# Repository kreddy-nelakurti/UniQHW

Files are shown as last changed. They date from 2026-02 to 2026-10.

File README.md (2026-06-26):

# UniQHW

The hardware repository for UQ Phone (UniQ)
The Corresponding software component can be found [https://github.com/Benksur/UniQOS](https://github.com/Benksur/UniQOS)

## About

**Supervised by:** Professor Pauline Pounds  
**Institution:** University of Queensland
<div align="center">

### UQ Phone Team (Year 1 - 2025)

| Name | Role |
|---|---|
| **Ty Behnke** | Firmware Design |
| **James Wood** | Hardware Design |
| **Caiyan Jin** | UI/UX Design |
</div>

Any Questions about the PCB and Schematics please direct them to [james.brian.wood@outlook.com](james.brian.wood@outlook.com)

## Production

The V0.2.0 PCB's must be made with the following specifications from JLCPCB

### Main PCB

This 6-Layer PCB must be made with the following

- Via Covering:	Epoxy Filled & Capped
- Min via hole size/diameter:	0.2mm/(0.3/0.35mm)

The following are also required if meeting the full size specifications of UniQ

- PCB Thickness:	0.8mm

Production versions should also be made with the following (Dependant on desired finish)

- Surface Finish:	ENIG Gold Thickness: 2U"
- PCB Color:	Black
- Silkscreen:	White

### Secondary PCB (Cellular Board)

This 4-Layer PCB must be made with the following

- PCB Thickness:	0.6mm
- Via Covering:	Epoxy Filled & Capped
- Min via hole size/diameter:	0.2mm/(0.3/0.35mm)
- Specify Stackup:	yes JLC04061H-2116

If Either the thickness or stackup is to change this boards traces should be redesigned for 50Ohm Impedance 

Production versions should also be made with the following (Dependant on desired finish)

- Surface Finish:	ENIG Gold Thickness: 2U"
- PCB Color:	Black
- Silkscreen:	White

## Current Issues And Improvements

The V0.2.0 PCB currently suffers from several issues which should be rectified on later versions:

- Batter Connector Location: move so it can be inserted and removed indpendantly of the secondary PCB
- SD/SIM Socket: Tie 3.3v SD card rail to insertion detection to prevent hot-plugging
- Debug Pads: Consider moving to provide easier access without interferance from screen
- Soft Power: Add soft power switch for more agressive power-off functionality and safer power-downs

The following may also be investigated for benefit 
- Improve Display: Ideally Display utilises a parellel interface, this needs more investigation
- Audio Volume: Current speaker is quiet, this should be investigated further to see if this can be remediated in firmware first
- USB Support: Add USB data connectivity to the device for file transfer or programming, this may resolve debug pad issues
- BT Audio: this poses significant challenges, although may be worth while, investigate further

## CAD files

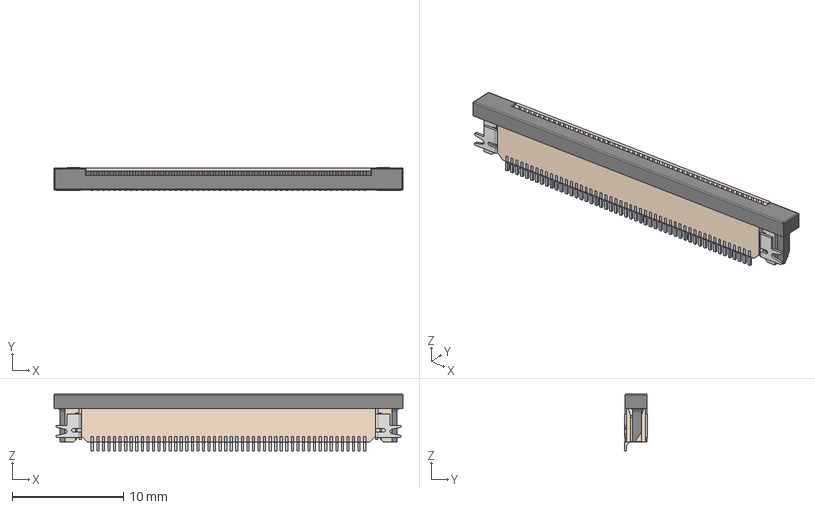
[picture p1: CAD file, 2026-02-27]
Components/6871XX14022_68715014022/6871XX14022_68715014022.step
31.4 x 2.10 x 5.10 mm
6871xx14022_PIN x 50
6871xx14022_Patte
6871xx14022_Patte_2
68715014022_CAP

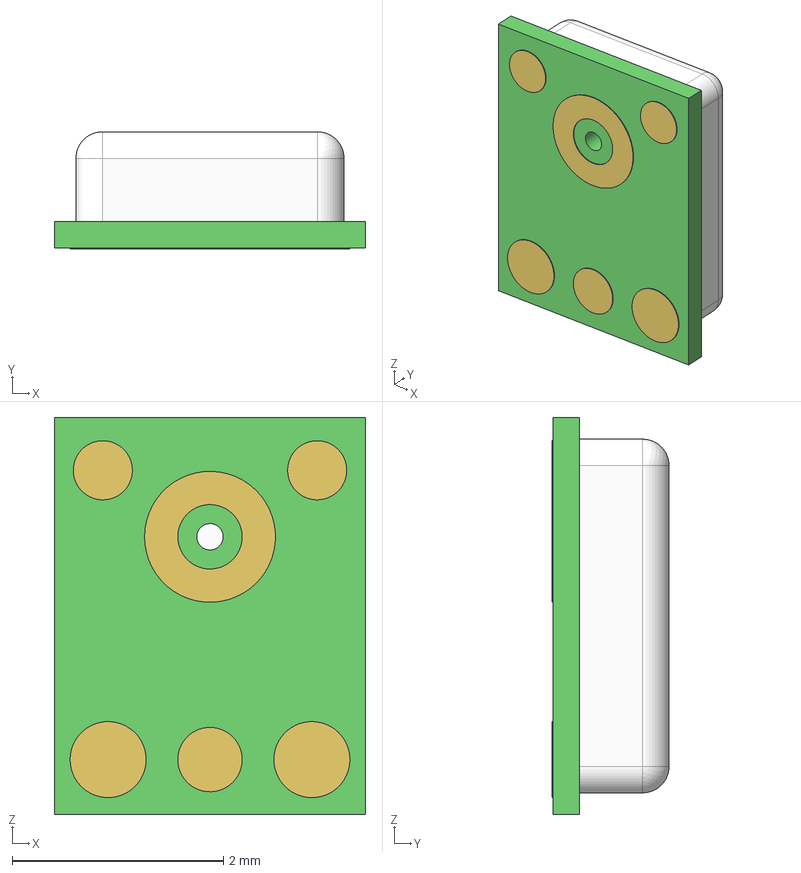
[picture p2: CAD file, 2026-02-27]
Components/AMM-3738-B-R/AMM-3738-B-R.step
2.95 x 1.11 x 3.76 mm

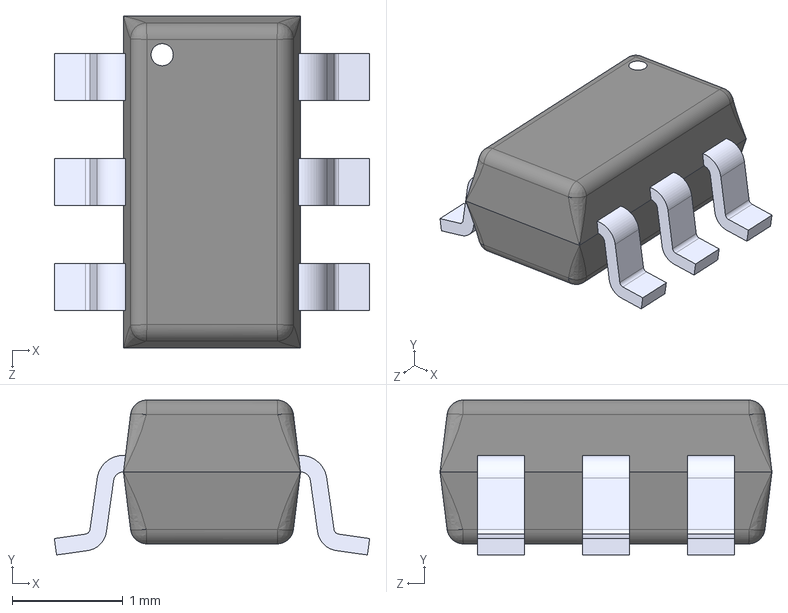
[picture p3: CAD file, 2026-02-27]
Components/BCR420UW6-7/BCR420UW6-7.step
2.85 x 1.40 x 3.00 mm

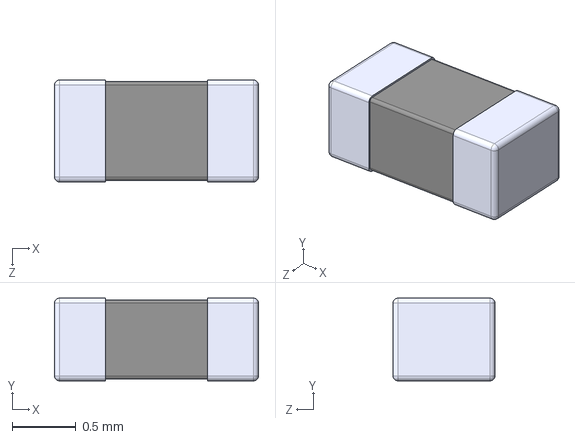
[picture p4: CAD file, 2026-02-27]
Components/BLM18SG221TN1D/BLM18SG221TN1D.step
1.60 x 0.65 x 0.8 mm

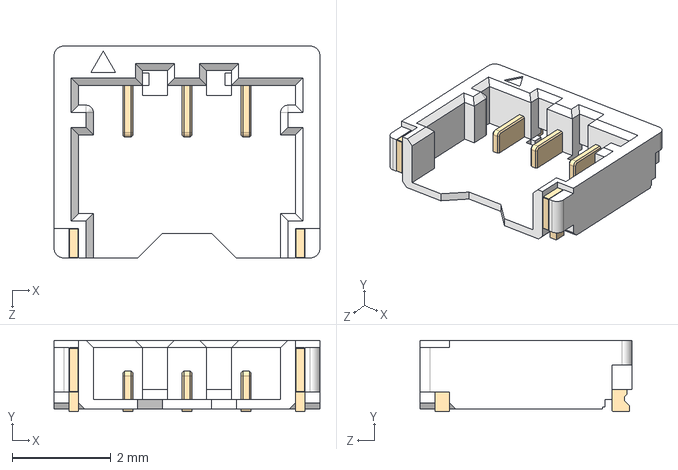
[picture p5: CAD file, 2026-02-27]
Components/BM03B-ACHSS-GAN-TF_LF__SN_/BM03B-ACHSS-GAN-TF_LF__SN_.step
5.40 x 1.45 x 4.30 mm

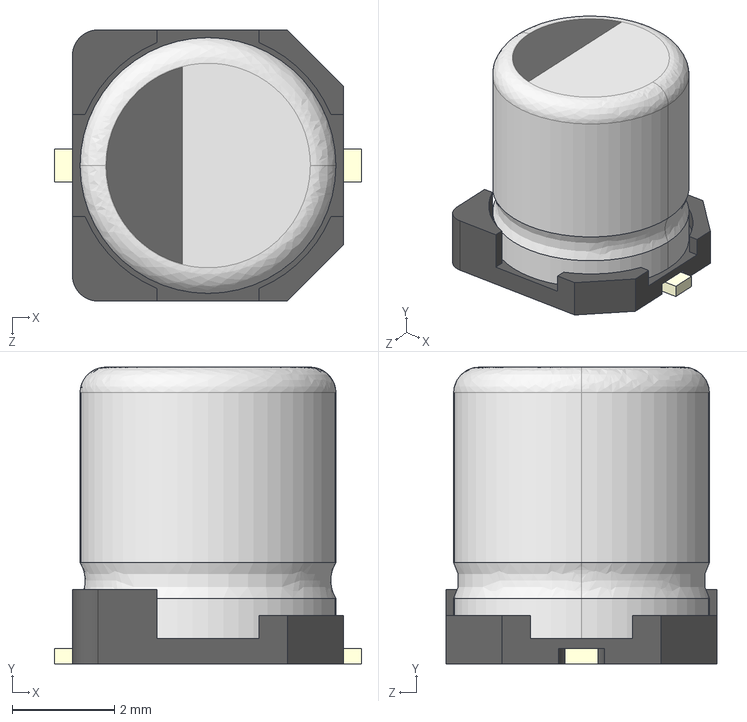
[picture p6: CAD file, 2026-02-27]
Components/Capacitors/EEE1CA470WR.step
6.00 x 5.80 x 5.30 mm

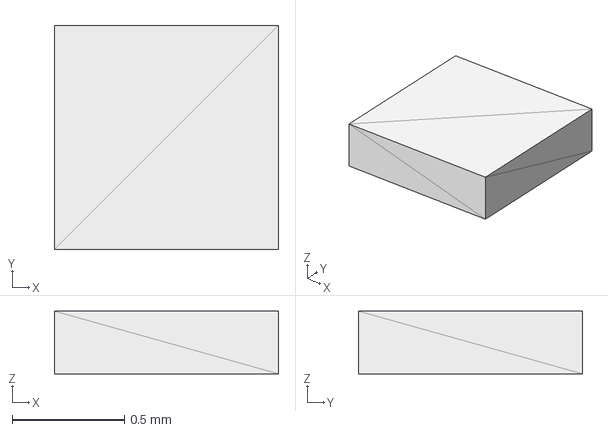
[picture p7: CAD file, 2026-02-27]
Components/custom_footprints_3d/XL-1010RGBC-WS2812B.step
1.00 x 1.00 x 0.28 mm

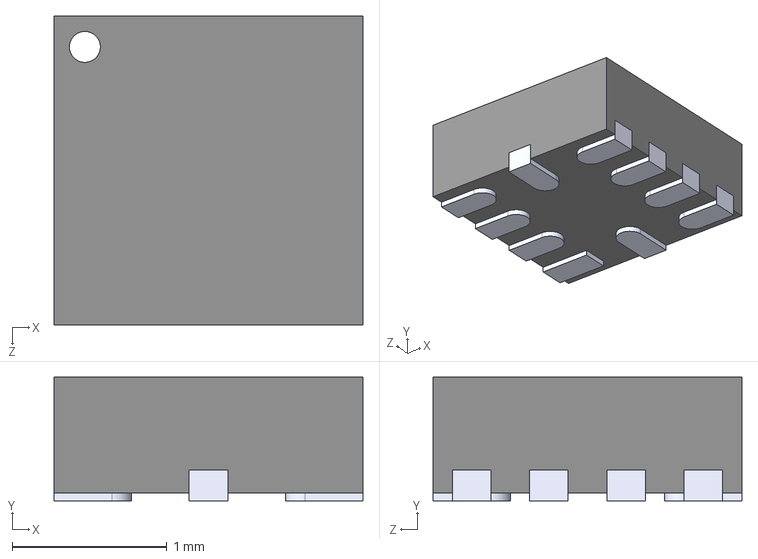
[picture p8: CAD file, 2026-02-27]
Components/DRV2603RUNR/DRV2603RUNR.step
2.00 x 0.8 x 2.00 mm

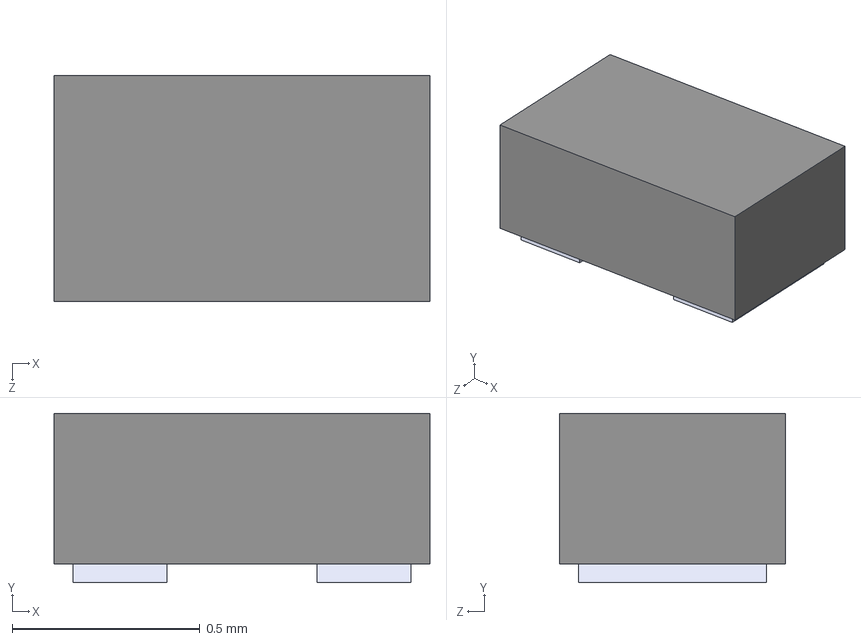
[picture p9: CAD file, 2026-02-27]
Components/ESD321DPYR/ESD321DPYR.step
1.00 x 0.45 x 0.6 mm

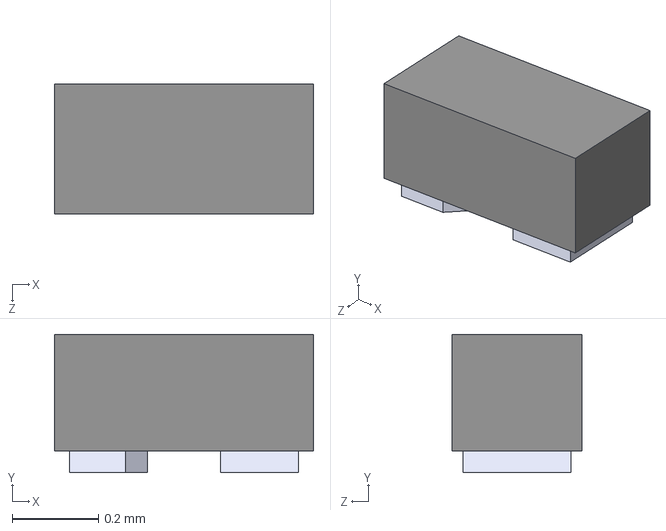
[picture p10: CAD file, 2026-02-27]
Components/ESD441DPLR/ESD441DPLR.step
0.6 x 0.32 x 0.3 mm

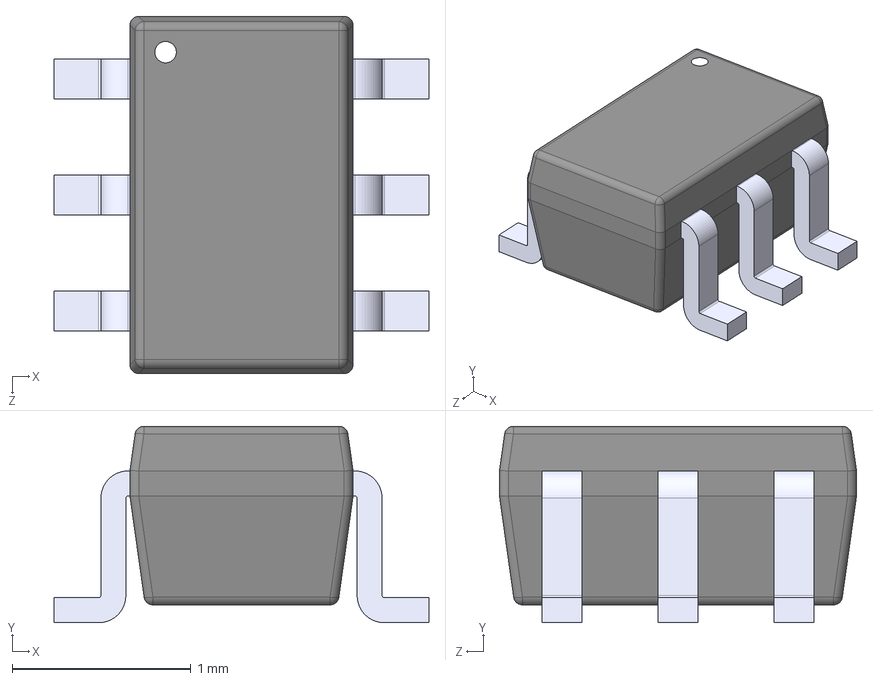
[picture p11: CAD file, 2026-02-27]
Components/ESDA6V1-5W6/ESDA6V1-5W6.step
2.10 x 1.10 x 2.00 mm

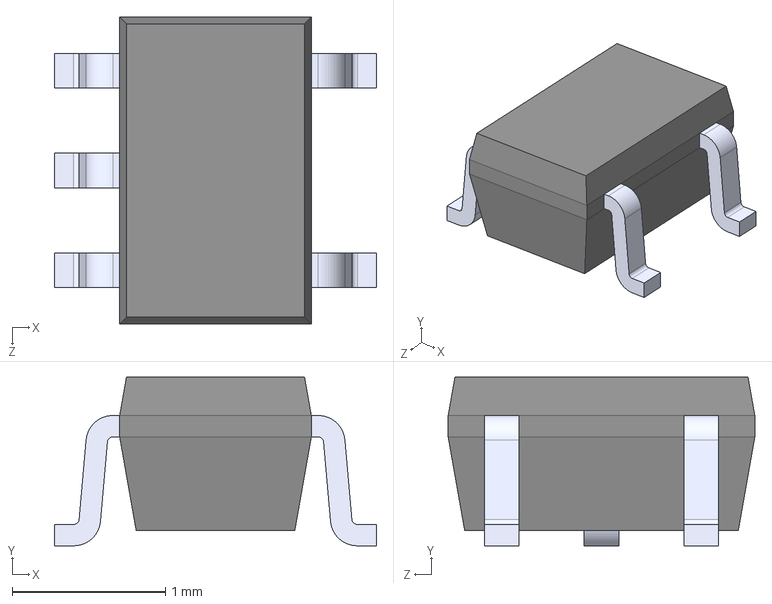
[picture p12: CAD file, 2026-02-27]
Components/ESDA6V1W5/ESDA6V1W5.step
2.10 x 1.10 x 2.00 mm

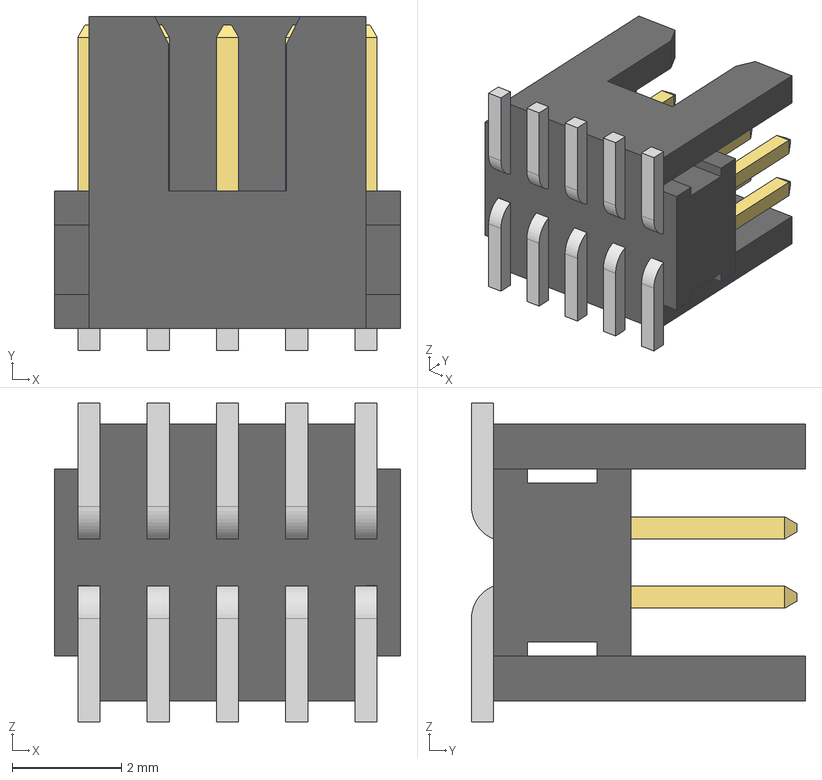
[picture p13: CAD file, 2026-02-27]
Components/FTSH-105-XX-X-DV/FTSH-105-XX-X-DV.step
6.35 x 6.12 x 5.84 mm
FTSH-105-01-L-DV-K-TR_body
FTSH-105-01-L-DV-K-TR_pins1
FTSH-105-01-L-DV-K-TR_pins2

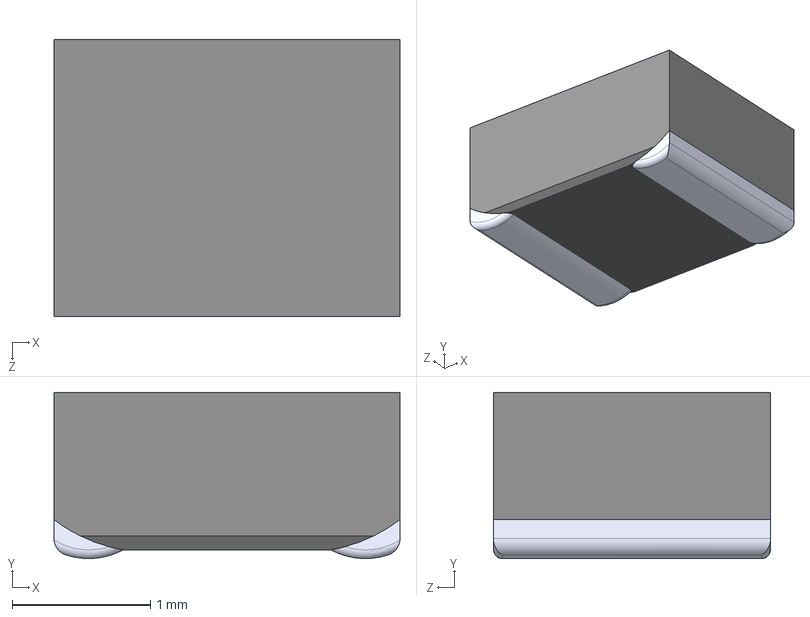
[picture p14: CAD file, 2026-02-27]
Components/Inductors/MAMK2520T3R3M.step
2.50 x 1.20 x 2.00 mm

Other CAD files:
Components/KP15B-6S-SF_800_/KP15B-6S-SF_800_.step
Components/LightOn-LEDs/LTST-C193KRKT-5A.step
Components/MMBT3904LP-7/MMBT3904LP-7.step
Components/MMBT3904LT1G/MMBT3904LT1G.step
Components/0532610371/0532610371.step
Components/1042391430/1042391430.step
Components/124018312112A/124018312112A_alt.step
Components/20279-001E-03/20279-001E-03.step
Components/503398-1892/503398-1892.step
Components/513382474/513382474.stp
Components/559092474/559092474.step
Components/BQ27441DRZR-G1A/BQ27441DRZR-G1A.step
Components/LP414565.step
Components/MAX17048G_T10/MAX17048G_T10.step
Components/MCP73871-2CCI_ML/MCP73871-2CCI_ML.step
Components/MMSZ5231BT1G/SOD-123_ONS.step
Components/MPZ2012S221AT000/MPZ2012S221AT000.step
Components/PCA9306DQER/PCA9306DQER.step
Components/RC7620_1104625/5302491_asm.stp
Components/S3B-PH-SM4-TB_LF__SN_/S3B-PH-SM4-TB_LF__SN_.step
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

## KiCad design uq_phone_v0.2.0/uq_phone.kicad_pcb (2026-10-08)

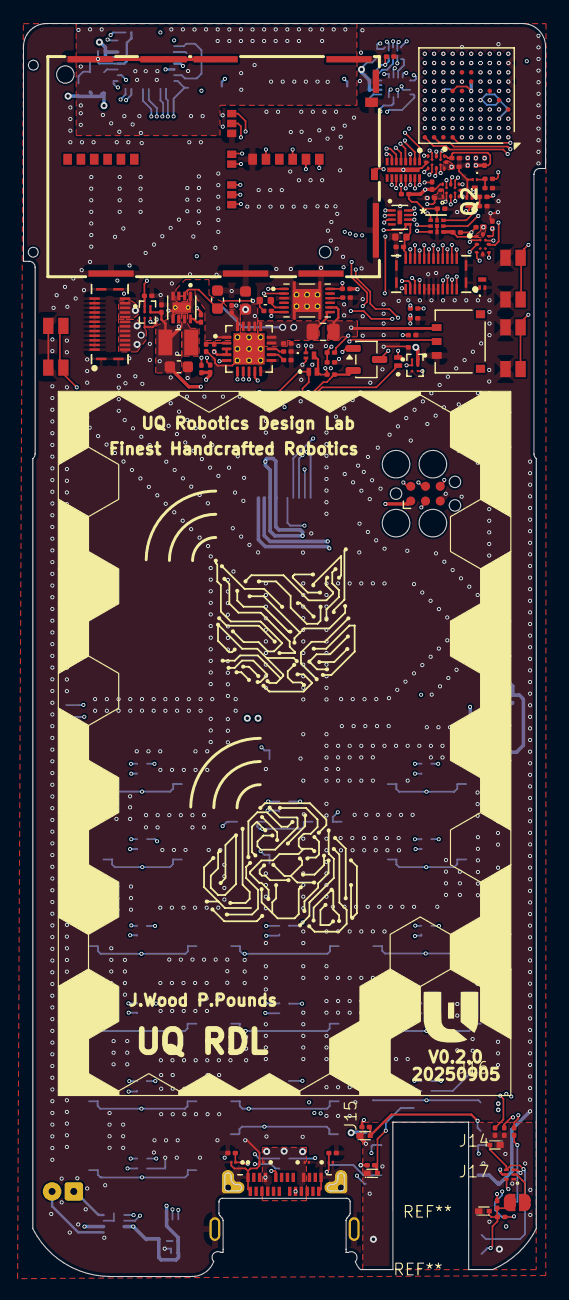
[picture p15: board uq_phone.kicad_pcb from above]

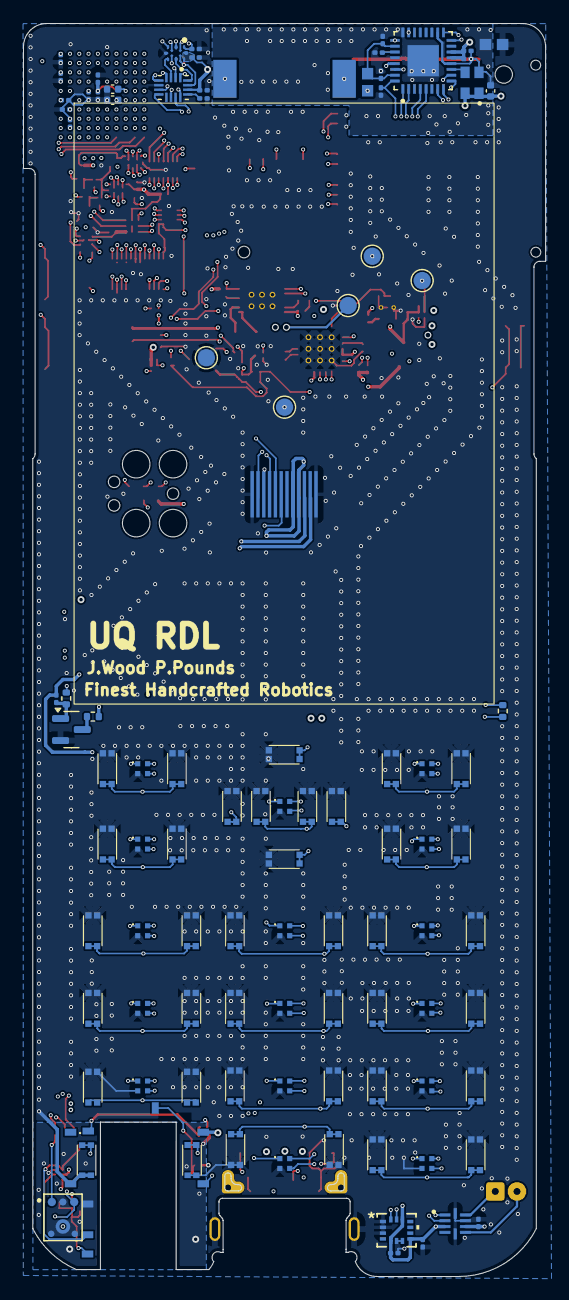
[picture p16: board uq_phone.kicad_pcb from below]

Board: 6 copper layers, 45.0 x 108.0 mm, 200 parts (100 on the bottom side), 182 nets.

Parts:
ART: Art_large
C1, C3: 10uF; C_0603_1608Metric
C2: 22uF; C_0603_1608Metric
C4, C7, C14, C36, C39, C40, C41, C42, C43, C44: 4.7uF; C_0201_0603Metric
C5: 470pF; C_0402_1005Metric
C6, C22, C23, C30, C37, C45, C47, C48, C49: 1uF; C_0201_0603Metric
C15, C16, C17, C18, C19, C20, C21, C28, C29, C31, C32, C34, C35, C38, C50, C51, C54, C55, C56, C57, C58, C59, C60: 100nF; C_0201_0603Metric
C25, C26: 2.2uF; C_0402_1005Metric
C33: 33pF; C_0402_1005Metric
C46: 10nF; C_0402_1005Metric
D2, D12: BAT54LP-7; DESD3V3S1BL7B
D4, D5, D6, D7: ESD441DPLR; DIODFN60X30X32-2N
D8, D9, D10, D11: ESD5451X; WBFBP-02C_L1.0-W0.6-BI
DISP1: HS20HS072RX; Display
FB1, FB2: BLM18SG221TN1D; BEADC1608X65N
J2: 124018312112A; AMPHENOL_124018312112A
J3: BM03B-ACHSS-GAN-TF_LF__SN_; JST_BM03B-ACHSS-GAN-TF_LF__SN_
J6: Conn_ARM_SWD_TagConnect_TC2030; Tag-Connect_TC2030-IDC-FP_2x03_P1.27mm_Vertical
J7, J9: 559092474; CON_559092474
J8: MCS-302S-C1; SIM-SMD_MCS-302S-C1
J13, J14, J15, J16, J17: Conn_01x01; Breakout_Mating_Pad
JP1: SolderJumper; SolderJumper-2_P1.3mm_Open_RoundedPad1.0x1.5mm
L1: 3.3uH; INDC2520X120N
LED1, LED3, LED4, LED5, LED6, LED7, LED8, LED9, LED10, LED11, LED12, LED13, LED14, LED15, LED16, LED17: XL-1010RGBC; XL-1010RGBC-WS2812B
LED2: XL-1010RGBC; XL-1010RGBC-Alt
M1: C08-00A; Motor_8mm
MK1: AMM-3738-B-R; MIC_AMM-3738-B-R
OSC1: OT7EL89CJI-111YLC-19.2M; OSC-SMD_4P-L2.0-W1.6-BL
Q1: MMBT3904LP-7; DFN101X61X53-3N
Q2, Q5, Q6: MMBT3904LP-7; MMBT3904LP7
Q3: S8050; SOT-23
Q4: DMP2035U-7; SOT-23-3
R1, R7, R11, R28, R29, R30: 100k; R_0201_0603Metric
R2, R3, R6: 5.1k; R_0201_0603Metric
R4, R16, R17, R22, R31: 4.7k; R_0201_0603Metric
R5: 270k; R_0201_0603Metric
R8, R20, R21, R23, R24, R25, R33, R37: 10k; R_0201_0603Metric
R9: 10m; R_0805_2012Metric
R10, R36: 2.2k; R_0201_0603Metric
R18, R19, R34: 47k; R_0201_0603Metric
R26: 1k; R_0402_1005Metric
R27: 5R; R_0402_1005Metric
R42: 330R; R_0402_1005Metric
SP1: MCABS-258-RC
SW1, SW2, SW3, SW4, SW5, SW7, SW8, SW9, SW10, SW11, SW12, SW13, SW14, SW15, SW17, SW18, SW19, SW20, SW21, SW23, SW24, SW25, SW26, SW27, SW28, SW29, SW30, SW31, SW32, SW33, SW34, SW35, SW36, SW37, SW38, SW39, SW40, SW41: SKTAAAE010
SW6, SW16, SW22: SKSCLCE010
TP1, TP2, TP3, TP5, TP6: TestPoint; TestPoint_Pad_D1.5mm
U1: TPS62162DSGR; SON50P200X200X80-9N
U2: MCP73871-2CCI_ML; QFN50P400X400X100-21N
U3: BQ27441DRZR-G1A; IC_BQ27441DRZR-G1A
U5: TCA9509MRVHR; RVH8_0P4X0P4
U6: STM32H723VGHx; TFBGA-100_8x8mm_Layout10x10_P0.8mm
U7, U15: TPS22964CYZPR; IC_SN74LVC2G34YZPR
U8: TPD3F303DQDR; SON40P170X135X80-9N
U9: AZV5001RA4-7; DFN1210P6X_L1.2-W1.0-P0.40-BL
U10: TPD8F003DQDR; SON40P135X330X80-17N
U11: LSM6DSVTR; LGA14-L_2P59X3P1X0P5_STM
U12: DRV2603RUNR; QFN50P200X200X80-10N
U13: TS3A5018RSVR; QFN40P260X180X55-16N
U14: NAU88C22YG; QFN50P500X500X80-33N
U17: TXU0204DTRR; DTR0012A-MFG
U18: TXU0304DTRR; DTR0012A-MFG
U19, U20: TXU0104DTRR; DTR0012A-MFG

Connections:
+1.8V: C28.1, C38.1, C41.1, C42.1, C46.1, C50.1, C55.1, C57.1, C59.1, J7.20, J7.21, J7.22, J7.23, OSC1.1 (Tri-state), OSC1.4 (VDD), U5.1 (VCCA), U5.5 (EN), U9.5 (Vcc), U13.14 (V+), U14.13 (VDDC), U14.14 (VDDB), U17.11 (VCCB), U17.12 (OE), U18.1 (VCCA), U18.12 (OE), U19.11 (VCCB), U19.12 (OE), U20.1 (VCCA), U20.12 (OE)
+3.3V: C2.1, C14.1, C15.2, C16.2, C17.2, C18.2, C19.2, C21.2, C22.1, C29.1, C30.1, C34.1, C35.1, C51.1, C54.1, C56.1, C58.1, C60.1, DISP1.8 (IOVCC), DISP1.9 (VCC), FB2.1, J6.1 (VCC), L1.2, R1.2, R4.2, R6.2, R22.2, R23.2, R24.2, R25.2, TP2.1, U1.6 (VOS), U5.8 (VCCB), U6.B2 (VBAT), U6.D2 (VDD), U6.F4 (VDD), U6.F5 (VDD), U6.F7 (PDR_ON), U6.H1 (VDDA), U6.K1 (VDD), U7.A2 (VIN), U7.B2 (VIN), U11.5 (VDD_IO), U11.8 (VDD), U11.12 (CS), U12.3 (LRA/~ERM), U12.7 (VDD), U15.A2 (VIN), U15.B2 (VIN), U17.1 (VCCA), U18.11 (VCCB), U19.1 (VCCA), U20.11 (VCCB)
+3.3V_SW: C31.1, DISP1.10 (LEDA), LED1.2 (VDD), LED2.2 (VDD), LED3.2 (VDD), LED4.2 (VDD), LED5.2 (VDD), LED6.2 (VDD), LED7.2 (VDD), LED8.2 (VDD), LED9.2 (VDD), LED10.2 (VDD), LED11.2 (VDD), LED12.2 (VDD), LED13.2 (VDD), LED14.2 (VDD), LED15.2 (VDD), LED16.2 (VDD), LED17.2 (VDD), R21.2, TP5.1, U15.A1 (VOUT), U15.B1 (VOUT)
AGND: C37.1, C39.2, C40.2, C43.2, C44.2, C45.2, D8.1, D9.1, D10.1, D11.1, FB1.2, J14.1, MK1.2 (GND), MK1.3 (GND__1), MK1.5 (GND__2), MK1.6_1 (GND__3), MK1.6_2 (GND__4), U9.1 (GND), U9.3 (G_Detect), U14.24 (VSSSPK), U14.28 (VSSA), U14.33 (EXP)
AUD_BCLK: U13.5 (COM2), U14.8 (BCLK)
AUD_IN: U13.7 (COM3), U14.9 (ADCOUT)
AUD_OUT: U13.10 (COM4), U14.10 (DACIN)
AUD_SCL: U5.2 (SCLA), U14.16 (SCLK)
AUD_SDA: U5.3 (SDAA), U14.17 (SDIO)
AUD_SW_H: U6.K10 (PD12), U19.2 (A1)
AUD_SW_L: R28.2, U13.15 (IN), U19.10 (B1Y)
AUD_SYNC: U13.2 (COM1), U14.7 (FS)
BAT_THERM: J3.2, U2.5 (THERM)
DISP_BL: R26.2, U6.J3 (PA6)
DISP_CS: DISP1.2 (CS), U6.J8 (PB13)
DISP_DC: DISP1.3 (RS), U6.H8 (PD14)
DISP_LEDK: DISP1.11 (LEDK), R27.2
DISP_RESET: DISP1.6 (RESET), U6.G8 (PD15)
DISP_SCL: DISP1.4 (SCL), U6.J6 (PE12)
DISP_SDA: DISP1.5 (SDA), U6.G7 (PE14)
FUEL_GPO: R6.1, U3.12 (GPOUT), U6.G9 (PD11)
GND: C1.1, C2.2, C3.2, C4.2, C5.2, C6.2, C7.2, C14.2, C15.1, C16.1, C17.1, C18.1, C19.1, C20.1, C21.1, C22.2, C23.2, C25.2, C26.2, C28.2, C29.2, C30.2, C31.2, C32.2, C33.2, C34.2, C35.2, C38.2, C41.2, C42.2, C46.2, C50.2, C51.2, C54.2, C55.2, C56.2, C57.2, C58.2, C59.2, C60.2, D4.2, D5.2, D6.2, D7.2, DISP1.1 (GND), DISP1.12 (GND), FB1.1, J2.A1 (GND_A), J2.A12 (GND_A__1), J2.B1 (GND_B), J2.B12 (GND_B__1), J2.SH1 (SHIELD), J2.SH2 (SHIELD__1), J2.SH3 (SHIELD__2), J2.SH4 (SHIELD__3), J3.1, J6.5 (GND), J7.1, J7.2, J7.3, J7.4, J7.5, J7.6, J7.7, J7.8, J7.9, J7.10, J7.11, J7.12, J7.24, J7.P1, J7.P2, J7.P3, J7.P4, J8.6 (VSS), J8.12 (SIM_1_GND), J8.22 (S/GND), J8.23 (GND), J9.5, J9.6, J9.7, J9.8, J9.P1, J9.P2, J9.P3, J9.P4, LED1.3 (GND), LED2.3 (GND), LED3.3 (GND), LED4.3 (GND), LED5.3 (GND), LED6.3 (GND), LED7.3 (GND), LED8.3 (GND), LED9.3 (GND), LED10.3 (GND), LED11.3 (GND), LED12.3 (GND), LED13.3 (GND), LED14.3 (GND), LED15.3 (GND), LED16.3 (GND), LED17.3 (GND), OSC1.2 (GND), Q1.2, Q2.2, Q3.2, Q5.2, Q6.2, R2.1, R3.1, R7.1, R8.1, R10.2, R11.1, R18.1, R19.1, R20.1, R28.1, R29.1, R33.1, R34.1, SW1.2, SW1.4, SW2.2, SW2.4, SW3.2, SW3.4, SW4.2, SW4.4, SW5.2, SW5.4, SW6.3, SW6.4, SW7.2, SW7.4, SW8.2, SW8.4, SW9.2, SW9.4, SW10.2, SW10.4, SW11.2, SW11.4, SW12.2, SW12.4, SW13.2, SW13.4, SW14.2, SW14.4, SW15.2, SW15.4, SW16.3, SW16.4, SW17.2, SW17.4, SW18.2, SW18.4, SW19.2, SW19.4, SW20.2, SW20.4, SW21.2, SW21.4, SW22.1, SW22.2, SW23.2, SW23.4, SW24.2, SW24.4, SW25.2, SW25.4, SW26.2, SW26.4, SW27.2, SW27.4, SW28.2, SW28.4, SW29.2, SW29.4, SW30.2, SW30.4, SW31.2, SW31.4, SW32.2, SW32.4, SW33.2, SW33.4, SW34.2, SW34.4, SW35.2, SW35.4, SW36.2, SW36.4, SW37.2, SW37.4, SW38.2, SW38.4, SW39.2, SW39.4, SW40.2, SW40.4, SW41.2, SW41.4, TP6.1, U1.1 (PGND), U1.4 (AGND), U1.5 (FB), U1.9 (EXP), U2.10 (VSS__1), U2.11 (VSS), U2.21 (EP), U3.3 (VSS), U3.13 (EXP), U5.4 (GND), U5.9 (EPAD), U6.C2 (VSS), U6.E4 (VSS), U6.E5 (VSS), U6.E6 (VSS), U6.G1 (VSSA), U6.J1 (VSS), U7.C1 (GND), U8.9 (GND), U10.17 (GND), U11.1 (SDO/SA0), U11.2 (SDX), U11.3 (SCX), U11.6 (GND), U11.7 (GND), U12.5 (GND), U12.8 (GND__1), U12.10 (GND__2), U13.6 (GND), U14.12 (VSSD), U14.18 (MODE), U15.C1 (GND), U17.6 (GND), U18.6 (GND), U19.6 (GND), U20.6 (GND)
HP_DET: U9.6 (OUT), U20.5 (A4)
HP_DET_MCU: U6.J10 (PD13), U20.7 (B4Y)
HP_LEFT: C48.1, U14.30 (LHP)
HP_LEFT_DET: D8.2, J17.1, U9.4 (L_Detect)
HP_MIC: C47.1, U14.4 (RMICP)
HP_MIC_GND: C45.1, U14.5 (RMICN)
HP_RIGHT: C49.1, U14.29 (RHP)
LED_DATA: R42.2, U6.K2 (PA3)
MCP_OUT: C4.1, Q4.2 (S), R30.1, U2.1 (OUT), U2.20 (OUT__1)
MCP_PG: U2.6 (~PG), U6.G10 (PB15)
MCP_STAT1: R24.1, U2.8 (STAT1/*LBO), U6.H10 (PB14)
MCP_STAT2: R23.1, U2.7 (STAT2), U6.H9 (PD10)
MCU_AUD_BCLK_H: U6.H3 (PA5), U19.5 (A4)
MCU_AUD_BCLK_L: U13.3 (NC2), U19.7 (B4Y)
MCU_AUD_OUT_L: U13.12 (NC4), U19.8 (B3Y)
MCU_AUD_OUT_L_H: U6.K3 (PA7), U19.4 (A3)
MCU_AUD_SYNC_H: U6.G3 (PA4), U19.3 (A2)
MCU_AUD_SYNC_L: U13.16 (NC1), U19.9 (B2Y)
MCU_CTS: U6.C10 (PA11), U17.4 (A3Y)
MCU_DCD: U6.C7 (PD3), U18.8 (B3Y)
MCU_DSR: U6.D9 (PA8), U18.9 (B2Y)
MCU_DTR: U6.D8 (PD0), U18.7 (B4)
MCU_PWR_LATCH: R31.2, U6.J4 (PB0)
MCU_RI: U6.F10 (PC6), U18.10 (B1Y)
MCU_RTS: U6.B10 (PA12), U17.3 (A2)
MCU_RXD: U6.D10 (PA10), U17.5 (A4Y)
MCU_TXD: U6.C9 (PA9), U17.2 (A1)
MIC_BIAS: C44.1, MK1.4 (VDD), R36.2, U14.32 (MICBIAS)
MIC_GND: C37.2, U14.2 (LMICN)
MIC_OUT: C36.2, U14.1 (LMICP)
MIC_PIN: C47.2, D11.2, J13.1, JP1.1 (A), R36.1
MOB_AUD_BCLK: J9.9, U13.4 (NO2)
MOB_AUD_IN: J9.10, U13.8 (NO3)
MOB_AUD_OUT: J9.11, U13.11 (NO4)
MOB_AUD_SYNC: J9.12, U13.1 (NO1)
MOB_CTS: J9.18, U17.8 (B3)
MOB_DCD: J9.14, U18.4 (A3)
MOB_DSR: J9.15, U18.3 (A2)
MOB_DTR: J9.13, U18.5 (A4Y)
MOB_PWR: J9.1, Q1.3
MOB_PWR_CTL: R16.2, U6.A2 (PC13)
MOB_RI: J9.20, U18.2 (A1)
MOB_RST: J9.2, Q2.3
MOB_RST_CTL: R17.2, U6.A1 (PC14)
MOB_RTS: J9.17, U17.9 (B2Y)
MOB_RXD: J9.19, U17.7 (B4)
MOB_SAFE_PWR_REMOVE_H: U6.J9 (PD9), U20.9 (B2Y)
MOB_SAFE_PWR_REMOVE_L: J9.3, U20.3 (A2)
MOB_TXD: J9.16, U17.10 (B1Y)
MOB_WAKE_H: U6.K9 (PD8), U20.10 (B1Y)
MOB_WAKE_L: J9.4, U20.2 (A1)
unnamed: C25.1, U6.E7 (VCAP)
unnamed: C26.1, U6.F8 (VCAP)
unnamed: D2.2 (A), Q4.1 (G), Q5.3, R30.2
unnamed: D2.1 (K), D12.1 (K), SW22.3, SW22.4
unnamed: D7.1, J2.A5 (CC1), R2.2
unnamed: D6.1, J2.B5 (CC2), R3.2
unnamed: J8.2 (CD/DAT3), U10.15 (CH2_OUT)
unnamed: J8.5 (CLK), U10.13 (CH4_OUT)
unnamed: J8.3 (CMD), U10.14 (CH3_OUT)
unnamed: J8.7 (DAT0), U10.11 (CH6_OUT)
unnamed: J8.8 (DAT1), U10.10 (CH7_OUT)
unnamed: J8.1 (DAT2), U10.16 (CH1_OUT)
unnamed: J8.11 (SIM_1_CLK), U8.2 (CLK_OUT)
unnamed: J8.14 (SIM_1_DATA), U8.3 (DATA2_OUT)
unnamed: J8.10 (SIM_1_RST), U8.1 (DATA1_OUT)
unnamed: C49.2, D10.2, J15.1
unnamed: C48.2, D9.2, J16.1
unnamed: JP1.2 (B), U9.2 (MIC)
unnamed: LED1.4 (DI), LED5.1 (DO)
unnamed: LED1.1 (DO), LED2.4 (DI)
unnamed: LED3.4 (DI), LED8.1 (DO)
unnamed: LED3.1 (DO), LED4.4 (DI)
unnamed: LED4.1 (DO), LED5.4 (DI)
unnamed: LED6.1 (DO), LED7.4 (DI)
unnamed: LED7.1 (DO), LED8.4 (DI)
unnamed: LED9.1 (DO), LED10.4 (DI)
unnamed: LED10.1 (DO), LED11.4 (DI)
unnamed: LED6.4 (DI), LED11.1 (DO)
unnamed: LED12.4 (DI), LED17.1 (DO)
unnamed: LED12.1 (DO), LED13.4 (DI)
unnamed: LED13.1 (DO), LED14.4 (DI)
unnamed: LED9.4 (DI), LED14.1 (DO)
unnamed: LED15.4 (DI), R42.1
unnamed: LED15.1 (DO), LED16.4 (DI)
unnamed: LED16.1 (DO), LED17.4 (DI)
unnamed: M1.1 (+), U12.9 (OUT_P)
unnamed: M1.2 (-), U12.6 (OUT_M)
unnamed: C36.1, MK1.1 (OUTPUT)
unnamed: OSC1.3 (OUT), U14.11 (MCLK)
unnamed: Q1.1, R16.1, R18.2
unnamed: Q2.1, R17.1, R19.2
unnamed: Q3.1, R21.1, R26.1
unnamed: Q3.3, R27.1
unnamed: Q5.1, R31.1, R34.2
unnamed: Q6.1, R37.1
unnamed: R1.1, U1.8 (PG)
unnamed: L1.1, U1.7 (SW)
unnamed: R10.1, U2.13 (PROG1)
unnamed: R11.2, U2.12 (PROG3)
unnamed: R5.1, R7.2, U2.2 (VPCC)
unnamed: C6.1, J3.3, R9.1, U3.6 (BAT), U3.8 (SRP)
unnamed: R8.2, U3.10 (BIN)
unnamed: C5.1, U3.5 (VDD)
unnamed: R20.2, U6.D5 (BOOT0)
unnamed: R33.2, U13.13 (~EN)
unnamed: C39.1, C40.1, FB2.2, U14.26 (VDDSPK), U14.31 (VDDA)
unnamed: C43.1, U14.27 (VREF)
PB_0: SW34.1, SW34.3, SW39.1, SW39.3, U6.A3 (PE2)
PB_1: SW24.1, SW24.3, SW28.1, SW28.3, U6.C3 (PE4)
PB_2: SW25.1, SW25.3, SW29.1, SW29.3, U6.A5 (PB7)
PB_3: SW26.1, SW26.3, SW30.1, SW30.3, U6.A6 (PB4(NJTRST))
PB_4: SW12.1, SW12.3, SW18.1, SW18.3, U6.C1 (PH0)
PB_5: SW13.1, SW13.3, SW19.1, SW19.3, U6.C5 (PB5)
PB_6: SW14.1, SW14.3, SW20.1, SW20.3, U6.B6 (PD5)
PB_7: SW1.1, SW1.3, SW7.1, SW7.3, U6.D3 (PE5)
PB_8: SW2.1, SW2.3, SW8.1, SW8.3, U6.C4 (PE1)
PB_9: SW3.1, SW3.3, SW9.1, SW9.3, U6.B5 (PB6)
PB_CALL: SW36.1, SW36.3, SW41.1, SW41.3, U6.B1 (PC15)
PB_DPAD_DOWN: SW17.1, SW17.3, U6.B3 (PE3)
PB_DPAD_LEFT: SW37.1, SW37.3, U6.G4 (PC4)
PB_DPAD_RIGHT: SW32.1, SW32.3, U6.C6 (PD6)
PB_DPAD_SELECT: SW5.1, SW5.3, SW11.1, SW11.3, U6.F1 (PC0)
PB_DPAD_UP: SW23.1, SW23.3, U6.F2 (PC1)
PB_END_CALL: SW15.1, SW15.3, SW21.1, SW21.3, U6.D6 (PD7)
PB_HASH: SW35.1, SW35.3, SW40.1, SW40.3, U6.D4 (PE0)
PB_MENU_L: SW27.1, SW27.3, SW31.1, SW31.3, U6.G2 (PA0)
PB_MENU_R: SW4.1, SW4.3, SW10.1, SW10.3, U6.D7 (PD4)
PB_STAR: SW33.1, SW33.3, SW38.1, SW38.3, U6.E3 (PE6)
PB_VOL_DOWN: SW16.1, SW16.2, U6.H2 (PA1)
PB_VOL_UP: SW6.1, SW6.2, U6.J2 (PA2)
POWER_SW: U6.E8 (PD1), U15.C2 (ON)
PWR_BUTTON_SENSE: D12.2 (A), U6.K8 (PB12)
REG_VIN_SW: C1.2, Q4.3 (D), U1.2 (VIN), U1.3 (EN)
RST: C20.2, J6.3 (~RESET), U6.E1 (NRST)
SCL: R22.1, U3.2 (SCL), U5.7 (SCLB), U6.B4 (PB8), U11.13 (SCL)
SDA: R4.1, U3.1 (SDA), U5.6 (SDAB), U6.A4 (PB9), U11.14 (SDA)
SD_PWR_EN: R29.2, U6.J7 (PB10), U7.C2 (ON)
SD_VDD_SW: C23.1, J8.4 (VDD), U7.A1 (VOUT), U7.B1 (VOUT)
SIM_CLK: J9.22, U8.7 (CLK_IN)
SIM_DATA: J9.23, U8.6 (DATA2_IN)
SIM_RST: J9.21, U8.8 (DATA1_IN)
SIM_VDD: C32.1, C33.1, J8.9 (SIM_1_VCC), J9.24, U8.5 (VCC)
SPEAKER_N: SP1.-, U14.25 (LSPKOUT)
SPEAKER_P: SP1.+, U14.23 (RSPKOUT)
SWCLK: J6.4 (SWCLK), U6.A9 (PA14(JTCK)
SWDIO: J6.2 (SWDIO), U6.A10 (PA13(JTMS)
SWO: J6.6 (SWO), U6.A7 (PB3(JTDO)
VBAT: C7.1, J7.13, J7.14, J7.15, J7.16, J7.17, J7.18, J7.19, R9.2, TP3.1, U2.14 (VBAT__1), U2.15 (VBAT), U2.16 (VBAT_SENSE), U3.7 (SRN)
VIB_EN: U6.K5 (PE9), U12.1 (EN)
VIB_PWM: U6.K4 (PB1), U12.2 (PWM)
VUSB: C3.1, D4.1, D5.1, J2.A4 (VBUS_A), J2.A9 (VBUS_A__1), J2.B4 (VBUS_B), J2.B9 (VBUS_B__1), R5.2, TP1.1, U2.3 (SEL), U2.4 (PROG2), U2.9 (~TE), U2.17 (CE), U2.18 (IN), U2.19 (IN__1)
uSD_CLK: U6.C8 (PC12), U10.4 (CH4_IN)
uSD_CMD: U6.B7 (PD2), U10.3 (CH3_IN)
uSD_DAT0: U6.F9 (PC8), U10.6 (CH6_IN)
uSD_DAT1: U6.E9 (PC9), U10.7 (CH7_IN)
uSD_DAT2: U6.B9 (PC10), U10.1 (CH1_IN)
uSD_DAT3: U6.B8 (PC11), U10.2 (CH2_IN)
uSD_DET: U6.E10 (PC7), U10.5 (CH5_IN)
uSD_TRAY_DET: J8.21 (SW/CD), R25.1, R37.2, U6.K7 (PB11), U10.12 (CH5_OUT)

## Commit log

2026-02-27 Add libs, mainly SnapEDA
    [0532610371.step, 0786463001.step, 1042391430.step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]
2026-07-13 Implement D-1 MicroSD load switch
    [mcu.kicad_sch, power.kicad_sch, user_io.kicad_sch]
2026-07-14 Added Document hardware schematic blocks for explanations
    [audio.kicad_sch, keypad.kicad_sch, mcu.kicad_sch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]
2026-07-15 Regulator EN-controlled soft power latch prototype
    [keypad.kicad_sch, mcu.kicad_sch, power.kicad_sch]
2026-07-15 VIN Based Latching circuit - switch off power to reg
    [power.kicad_sch]
2026-07-17 Add shared tray detect for MCU and RC7620 SIM detection
    [mcu.kicad_sch, mobile.kicad_sch, user_io.kicad_sch]
2026-07-17 Move battery connector for improved access - pending
2026-07-24 Add soft power switch and update PCB design
    [keypad.kicad_sch, mcu.kicad_sch, power.kicad_sch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]
2026-07-30 Fix KiCad libraries and update soft power circuit
    [mcu.kicad_sch, mobile.kicad_sch, power.kicad_sch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]
2026-08-06 Route soft power switch
    [mcu.kicad_sch, soft_power_switch.kicad_sch, uq_phone.kicad_pcb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]
2026-08-06 Update PCB routing
    [uq_phone.kicad_pcb]
2026-08-09 Update SD card power routing
    [uq_phone.kicad_pcb]
2026-09-16 Add headphone breakout board and update main PCB
    [audio.kicad_sch, uq_phone.kicad_pcb, uq_phone_headphone_jack.kicad_pcb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]
2026-09-22 Updated main PCB
    [display.kicad_sch, uq_phone.kicad_pcb, uq_phone.step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]
2026-09-23 new display work
    [display.kicad_sch, uq_phone.kicad_sch, user_io.kicad_sch]
2026-10-08 Updated main PCB and headphone jack breakout board
    [uq_phone.kicad_pcb, uq_phone_headphone_jack.kicad_pcb]
2026-10-15 Save PCB and schematic before STM32 FMC pin remapping
2026-10-15 Complete STM32H723ZGI6 144-pin schematic and FMC mapping
2026-10-15 Revert "Complete STM32H723ZGI6 144-pin schematic and FMC mapping"
    This reverts commit c988dda79df5cbf87dce3ceded82a655262fe630.
2026-10-17 Prototype without GPIO expander
2026-10-17 Add GPIO expander and 16-bit FMC display schematic
2026-10-21 Add final UQ Phone v0.2.0 PCB design

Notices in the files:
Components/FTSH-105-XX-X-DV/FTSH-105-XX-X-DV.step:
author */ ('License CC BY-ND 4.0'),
